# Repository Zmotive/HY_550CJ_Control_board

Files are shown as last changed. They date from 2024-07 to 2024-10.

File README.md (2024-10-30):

# Overview #

Please review the license for use. 

This Project is still under development and not all features have been tested. As I work through the hardware I will continue to update. it is best to test this code will small actuators and another remote control unit prior to installing into an HY-550CJ. 

The HY-550CJ is a dangerous piece of equipment, any code that isn't tested should not be trusted as the machine is capable of serious injury to the user. In no way does the Authors or Contributors accept liability for damage to property or persons in use of this code or hardware. Care must be taken when using this repository. This same controller can be modified to fit other systems as it leverages the RC standard for control. It is best to test this on a safer piece of equipment (or remove the blades from the HY-550CJ prior to testing). 

This code is unable to control the output of the motors when the "Auto" Switch is open (in the off state). The Teensy outputs the power on its auto pin that then runs to the physical switch. This ensures that the device cannot override an operator's manual control. Unfortunately this switch must be located on the machine. 

[@ztokAutomates](https://www.youtube.com/@ztokautomates) will be covering safety of use of this equipment and hazards that operators, programmers, and contributors should be aware of prior to use.   

# Safety #

Do a risk assesment according to ISO 12100 to understand the risks. The following notes below are only a small subset of the most dangerous hazards associated with the machine.

* When working on the blades, disconnect the sparkplug to keep from unexpected engine startup.
* Never place yourself inbetween the machine and a fixed object. The crushing hazard is the one of the most dangerous hazards assocated with the base (not including the blades)
* It is possible to get entangled into the machine tracks, make sure to power off the machine and controller before working on the tracks. Do not underestimate the power and speed of unexpected movement.
* Do Not Ride the Machine. It does have enough power to move people on it but with all of the risks of the tracks, blades, and engine; there is no safe way to ride it. If the intent is to ride the machine then add that task to the risk assesment to understand what hazards you will need to protect from (including rollover).
* When doing the risk assesment ensure to take into account bystandards that will not know about any of these risks (people assume machines are safe and are not hazardous). It is the operator's reponsibilty to keep people safe and understand the hazards assocated with the machine (this is typically accomplished with signs).
* Only use the charger that came with the machine. The port on the machine to charge it is a standard IEC Plug used on 120VAC systems. This Plug on the equpment is actually a 12VDC circuit and plugging it into the wall can cause the frame to be engergized and destroy the control system within the machine and can lead to fire.
* This machine has not been evaluated by any NRTLs (Nationally Recoginized Testing Labratories, like NSF or UL). It is possible (although unlikely) that this system may catch fire if care is not taken.
* There is no rollover cutoff on the machine. if the machine rolls over it will damage the engine. Climbing hills can also damage the engine if constantly doing hills. Give the machine a break if doing a lot of hills. [Video Snipit](https://www.youtube.com/watch?v=2dOWbkyhdJA&t=2900s)
* There is a possibily of debris being ejected from under the machine, wear protective equipment when operating it. The most dangerous places to be are infront and behind the equipment. It can also be ejected from the sides. [It has reached over 10ft in my experience (standing behing it)](https://www.youtube.com/watch?v=2dOWbkyhdJA&t=3720s). Be mindeful of this when operating it.

## Limits ##
* Maximum flat pull force > 300 lbsf (the belts do not stop at this force)
* Maximum speed < ~ 300mm/s (1 ft/s)
* Maximum climb angle < 45 degrees in the forward direction.  

# Setup #
* The Teensy needs to be setup to disable being powered from the USB port to enable debugging under power. [Teensy Reference](https://www.pjrc.com/teensy/external_power.html)
* J1 on the board links the Board 5Vdc to the Motor and Input 5Vdc to power the controller and smaller motors. it should not be used when in the HY-550CJ since power comes from the motor controllers.

# Parts #
 
 [Mouser Project](https://www.mouser.com/ProjectManager/ProjectDetail.aspx?AccessID=017e74ae19)

 Teensy4.1 and GPS boards (2x for robot, 1x for base station) are seperate.
 [GPS Board](https://www.sparkfun.com/products/16481)

 Headers and Sockets included for Teensy and GPS boards.

 [HY-550CJ](https://www.alibaba.com/product-detail/FREE-SHIPPING-CE-EPA-Remote-Control_1600909334029.html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)

 [Base Station Radio 100mW 915Mhz](https://holybro.com/products/sik-telemetry-radio-v3?variant=41562952302781)

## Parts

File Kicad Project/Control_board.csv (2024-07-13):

Source: | C:\Users\Zack\Documents\AGV Board\Control_board\Control_board.kicad_sch
Date: | 7/12/2024 6:36:46 PM
Tool: | Eeschema (7.0.0)
Generator: | C:\Program Files\KiCad\7.0\bin\scripting\plugins/bom_csv_grouped_by_value.py
Component Count: | 55
Collated Components:
Item | Qty | Reference(s) | Value | LibPart | Footprint | Datasheet | DNP | Height | Manufacturer_Name | Manufacturer_Part_Number | Mouser Part Number | Mouser Price/Stock | Sim.Device | Sim.Pins
1 | 5 | 5VOut1, 12VOut1, EKill1, EStart1, SWA1 | Conn_01x02_Pin | Connector:Conn_01x02_Pin | Connector_Phoenix_MC_HighVoltage:PhoenixContact_MCV_1,5_2-G-5.08_1x02_P5.08mm_Vertical | ~
2 | 8 | A3C1, A3M1, A4C1, A4M1, IL1, IR1, ML1, MR1 | Conn_01x03_Pin | Connector:Conn_01x03_Pin | Connector_PinHeader_2.54mm:PinHeader_1x03_P2.54mm_Vertical | ~
3 | 2 | D1, D2 | 1N4001 | Diode:1N4001 | Diode_THT:D_DO-41_SOD81_P10.16mm_Horizontal | http://www.vishay.com/docs/88503/1n4001.pdf |  |  |  |  |  |  |  | D | 1=K 2=A
4 | 4 | IC1, IC2, IC3, IC4 | CNY74-2H | SamacSys:CNY74-2H | DIP762W56P254L977H470Q8N | https://componentsearchengine.com/Datasheets/2/CNY74-2H.pdf |  |  | 4.7 | Vishay | CNY74-2H | 782-CNY74-2H | https://www.mouser.co.uk/ProductDetail/Vishay-Semiconductors/CNY74-2H?qs=xCMk%252BIHWTZO%2Fp2dB7mb0lQ%3D%3D
5 | 2 | IMU1, Radio1 | Conn_01x04_Pin | Connector:Conn_01x04_Pin | Connector_PinHeader_2.54mm:PinHeader_1x04_P2.54mm_Vertical | ~
6 | 1 | J1 | Conn_01x02_Pin | Connector:Conn_01x02_Pin | Connector_PinHeader_2.54mm:PinHeader_1x02_P2.54mm_Vertical | ~
7 | 2 | K1, K5 | SR11-3V-200-2C | SamacSys:SR11-3V-200-2C | SR113V2002C | https://www.cuidevices.com/product/resource/sr11.pdf |  |  | 11.7 | CUI Devices | SR11-3V-200-2C | 179-SR11-3V-200-2C | https://www.mouser.co.uk/ProductDetail/CUI-Devices/SR11-3V-200-2C?qs=4ASt3YYao0Upd1omJxk2Og%3D%3D
8 | 1 | K2 | SR5-12V-200-1C | SamacSys:SR5-12V-200-1C | SR512V2001C | https://www.cuidevices.com/product/resource/sr5.pdf |  |  | 12.1 | CUI Devices | SR5-12V-200-1C | 179-SR5-12V-200-1C | https://www.mouser.co.uk/ProductDetail/CUI-Devices/SR5-12V-200-1C?qs=4ASt3YYao0WMNY1cu6cO0A%3D%3D
9 | 1 | K3 | SR5-3V-200-1C | :SR5-3V-200-1C_1 | SR53V2001C | https://www.cuidevices.com/product/resource/sr5.pdf |  |  | 12.1 | CUI Devices | SR5-3V-200-1C | 179-SR5-3V-200-1C | https://www.mouser.co.uk/ProductDetail/CUI-Devices/SR5-3V-200-1C?qs=4ASt3YYao0XB60H1Ojp4Wg%3D%3D
10 | 1 | K4 | SR5-3V-200-1C | SamacSys:SR5-3V-200-1C | SR53V2001C | https://www.cuidevices.com/product/resource/sr5.pdf |  |  | 12.1 | CUI Devices | SR5-3V-200-1C | 179-SR5-3V-200-1C | https://www.mouser.co.uk/ProductDetail/CUI-Devices/SR5-3V-200-1C?qs=4ASt3YYao0XB60H1Ojp4Wg%3D%3D
11 | 1 | LED1 | 550-1307-004F | SamacSys:550-1307-004F | 5501307004F | https://s3-us-west-2.amazonaws.com/catsy.557/C17646.pdf |  |  | 6.351 | Dialight | 550-1307-004F | 645-550-1307-004F | https://www.mouser.co.uk/ProductDetail/Dialight/550-1307-004F?qs=0KZIkTEbAAuDZRCbhcaU%252Bg%3D%3D
12 | 1 | LEFT-GPS1 | ~ | Boards:SparkFun_GPS-RTK | boards:Sparkfun GPS-RTK
13 | 1 | PS1 | THL_15-2411WI | SamacSys:THL_15-2411WI | THL152411WI | https://tracopower.com/thl15wi-datasheet/ |  |  | 10.66 | Traco Power | THL 15-2411WI | 495-THL15-2411WI | https://www.mouser.co.uk/ProductDetail/TRACO-Power/THL-15-2411WI?qs=vLWxofP3U2zTxW0y6%2FAPOg%3D%3D
14 | 1 | PWR_InF1 | Conn_01x03_Pin | Connector:Conn_01x03_Pin | Connector_Phoenix_MC_HighVoltage:PhoenixContact_MCV_1,5_3-G-5.08_1x03_P5.08mm_Vertical | ~
15 | 2 | R1, R3 | 750 | Device:R | Resistor_THT:R_Axial_DIN0411_L9.9mm_D3.6mm_P12.70mm_Horizontal | ~
16 | 1 | R2 | 6.8K | Device:R | Resistor_THT:R_Axial_DIN0411_L9.9mm_D3.6mm_P12.70mm_Horizontal | ~
17 | 1 | R4 | 1.6K | Device:R | Resistor_THT:R_Axial_DIN0411_L9.9mm_D3.6mm_P12.70mm_Horizontal | ~
18 | 4 | R5, R6, R18, R20 | 187 | Device:R | Resistor_THT:R_Axial_DIN0411_L9.9mm_D3.6mm_P12.70mm_Horizontal | ~
19 | 8 | R7, R8, R9, R10, R13, R14, R15, R16 | 10K | Device:R | Resistor_THT:R_Axial_DIN0411_L9.9mm_D3.6mm_P12.70mm_Horizontal | ~
20 | 4 | R11, R12, R17, R19 | 100 | Device:R | Resistor_THT:R_Axial_DIN0411_L9.9mm_D3.6mm_P12.70mm_Horizontal | ~
21 | 1 | RIGHT-GPS1 | ~ | :SparkFun_GPS-RTK_1 | boards:Sparkfun GPS-RTK
22 | 1 | U1 | Teensy4.1 | Teensy:Teensy4.1 | Teensy:Teensy41
23 | 2 | U2, U3 | 01530007Z | SamacSys:01530007Z | 01530007Z | http://m.littelfuse.com/~/media/commercial-vehicle/datasheets/automotive-fuse-holders/mini/littelfuse_fuse-holders-mini-153-pc-datasheet.pdf |  |  | 7 | LITTELFUSE | 01530007Z | 576-01530007Z | https://www.mouser.co.uk/ProductDetail/Littelfuse/01530007Z?qs=gu7KAQ731URFnx4B9aYM4g%3D%3D

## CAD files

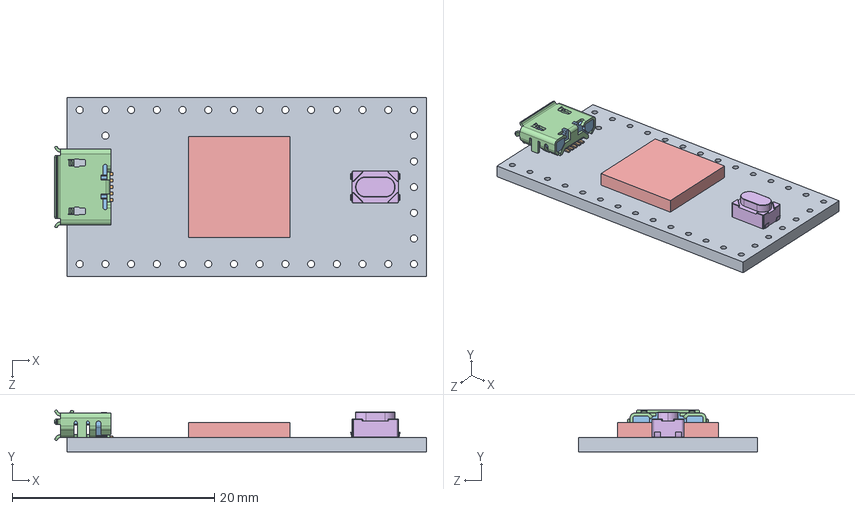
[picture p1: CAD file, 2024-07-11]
Kicad Project/asBuilts/teensy.pretty-master/teensy.pretty-master/Teensy_4.0_Assembly.STEP
36.8 x 4.12 x 17.7 mm
Teensy_4.0_PCB
Micro USB-B Female 5Pin SMD
NXP iMXRT1062
SKRPACE010 v4

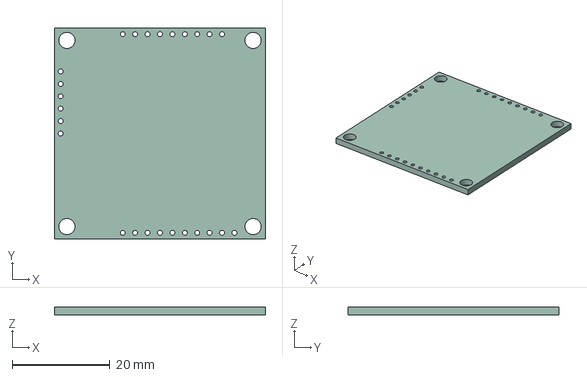
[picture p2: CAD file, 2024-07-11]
Kicad Project/asBuilts/Qwiic_GPS-RTK-SMA_-_ublox_ZED-F9P/Qwiic GPS-RTK-SMA - ublox ZED-F9P Template.step
43.2 x 43.2 x 1.60 mm

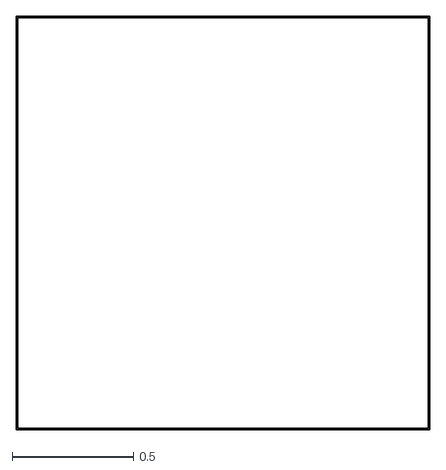
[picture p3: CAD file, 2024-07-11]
Kicad Project/asBuilts/Qwiic_GPS-RTK-SMA_-_ublox_ZED-F9P/Qwiic GPS-RTK-SMA - ublox ZED-F9P Template-Edge_Cuts.dxf
1.71 x 1.71

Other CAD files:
Kicad Project/asBuilts/Qwiic_GPS-RTK-SMA_-_ublox_ZED-F9P/Qwiic GPS-RTK-SMA - ublox ZED-F9P Template-F_Mask.dxf
Kicad Project/asBuilts/Qwiic_GPS-RTK-SMA_-_ublox_ZED-F9P/Qwiic GPS-RTK-SMA - ublox ZED-F9P Template-F_Silkscreen.dxf

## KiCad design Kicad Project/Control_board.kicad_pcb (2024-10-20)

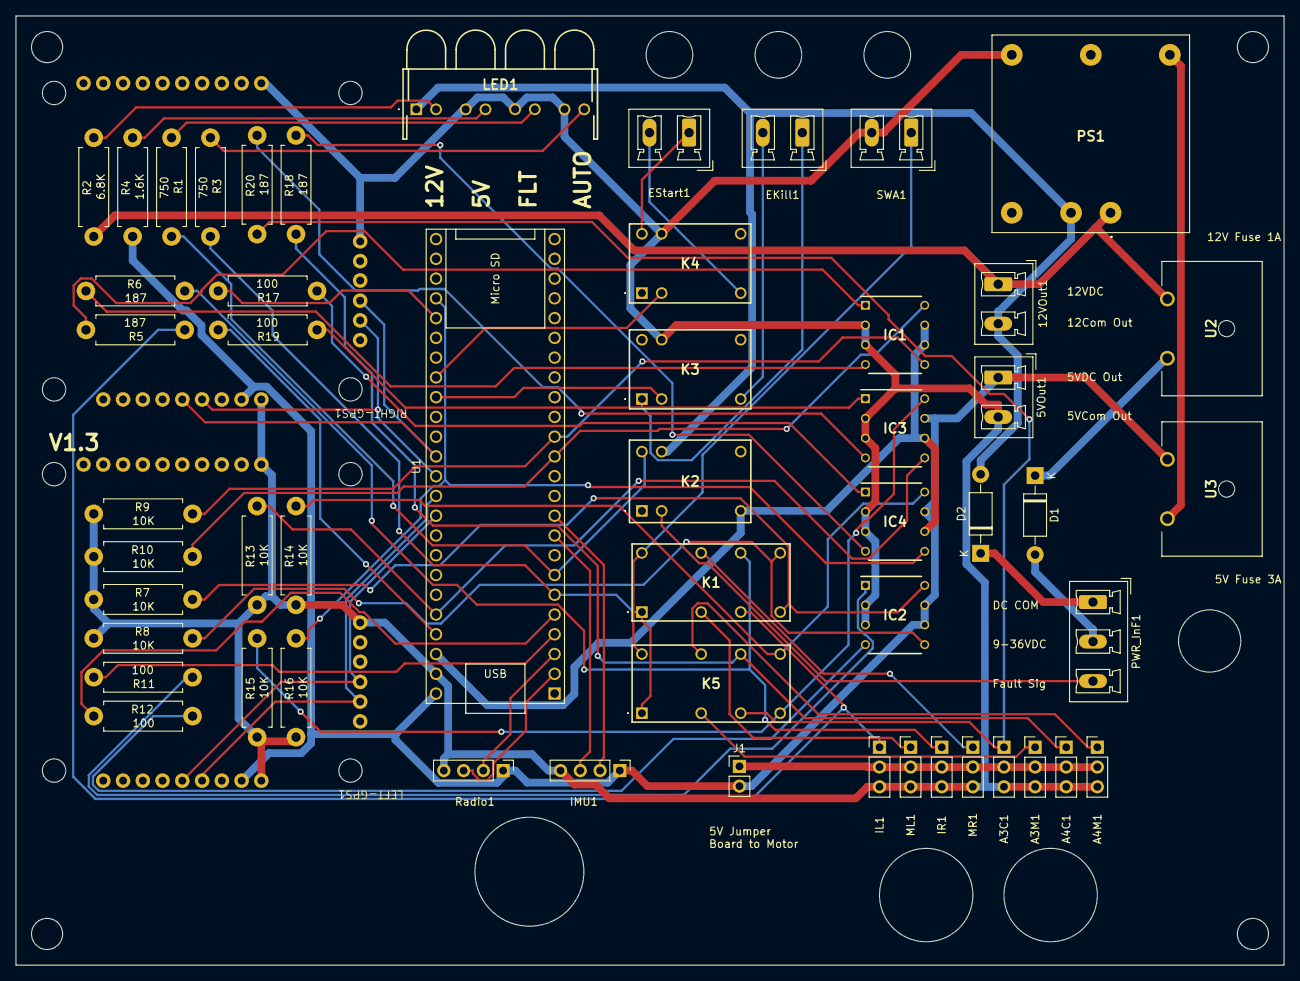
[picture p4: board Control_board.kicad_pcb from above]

Board: 2 copper layers, 163.0 x 122.0 mm, 55 parts (0 on the bottom side), 60 nets.

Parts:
5VOut1, 12VOut1: Conn_01x02_Pin; PhoenixContact_MCV_1,5_2-G-5.08_1x02_P5.08mm_Vertical
A3C1, A3M1, A4C1, A4M1: Conn_01x03_Pin; PinHeader_1x03_P2.54mm_Vertical
D1, D2: 1N4001; D_DO-41_SOD81_P10.16mm_Horizontal
EKill1: Conn_01x02_Pin; PhoenixContact_MCV_1,5_2-G-5.08_1x02_P5.08mm_Vertical
EStart1: Conn_01x02_Pin; PhoenixContact_MCV_1,5_2-G-5.08_1x02_P5.08mm_Vertical
IC1, IC2, IC3, IC4: CNY74-2H; DIP762W56P254L977H470Q8N
IL1: Conn_01x03_Pin; PinHeader_1x03_P2.54mm_Vertical
IMU1: Conn_01x04_Pin; PinHeader_1x04_P2.54mm_Vertical
IR1: Conn_01x03_Pin; PinHeader_1x03_P2.54mm_Vertical
J1: Conn_01x02_Pin; PinHeader_1x02_P2.54mm_Vertical
K1, K5: SR11-3V-200-2C; SR113V2002C
K2: SR5-12V-200-1C; SR512V2001C
K3, K4: SR5-3V-200-1C; SR53V2001C
LED1: 550-1307-004F; 5501307004F
LEFT-GPS1: Sparkfun GPS-RTK
ML1: Conn_01x03_Pin; PinHeader_1x03_P2.54mm_Vertical
MR1: Conn_01x03_Pin; PinHeader_1x03_P2.54mm_Vertical
PS1: THL_15-2411WI; THL152411WI
PWR_InF1: Conn_01x03_Pin; PhoenixContact_MCV_1,5_3-G-5.08_1x03_P5.08mm_Vertical
R1, R3: 750; R_Axial_DIN0411_L9.9mm_D3.6mm_P12.70mm_Horizontal_ZT
R2: 6.8K; R_Axial_DIN0411_L9.9mm_D3.6mm_P12.70mm_Horizontal_ZT
R4: 1.6K; R_Axial_DIN0411_L9.9mm_D3.6mm_P12.70mm_Horizontal_ZT
R5, R6, R18, R20: 187; R_Axial_DIN0411_L9.9mm_D3.6mm_P12.70mm_Horizontal_ZT
R7, R8, R9, R10, R13, R14, R15, R16: 10K; R_Axial_DIN0411_L9.9mm_D3.6mm_P12.70mm_Horizontal_ZT
R11, R12, R17, R19: 100; R_Axial_DIN0411_L9.9mm_D3.6mm_P12.70mm_Horizontal_ZT
RIGHT-GPS1: Sparkfun GPS-RTK
Radio1: Conn_01x04_Pin; PinHeader_1x04_P2.54mm_Vertical
SWA1: Conn_01x02_Pin; PhoenixContact_MCV_1,5_2-G-5.08_1x02_P5.08mm_Vertical
U1: Teensy4.1; Teensy41
U2, U3: 01530007Z

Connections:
3.3V: IC1.6 (CE_2), IC1.7 (CE_1), IC3.6 (CE_2), IC4.6 (CE_2), K2.3 (COM_1), U1.46 (3V3)
5VDC: 5VOut1.1, IC2.6 (CE_2), IC2.7 (CE_1), IC3.7 (CE_1), IC4.7 (CE_1), IMU1.1, J1.2, LEFT-GPS1.8 (5V), R4.1, RIGHT-GPS1.8 (5V), Radio1.1, U1.48 (VIN), U3.2
5VDC_A: PS1.3 (+VOUT), U3.1
12COM: D2.1 (K), PWR_InF1.1
12COM_C: 12VOut1.2, D2.2 (A), K2.5 (COIL_2), LED1.1 (K_GREEN_1), PS1.2 (-VIN_(GND))
12VDC: D1.2 (A), PWR_InF1.2
12VDC_A: D1.1 (K), U2.1
12VDC_C: 12VOut1.1, PS1.1 (+VIN_(VCC)), R2.1, U2.2
A3C_IN: IC3.5 (E_2), R13.2, U1.44 (22_A8_CTX1)
A3M_OUT: R19.2, U1.45 (23_A9_CRX1_MCLK1)
A4C_IN: IC4.5 (E_2), R16.2, U1.28 (36_CS)
A4M_OUT: R17.2, U1.29 (37_CS)
COM: 5VOut1.2, A3C1.3, A3M1.3, A4C1.3, A4M1.3, IC1.2 (C_1), IC1.3 (C_2), IC2.2 (C_1), IC2.3 (C_2), IC3.2 (C_1), IC3.3 (C_2), IC4.2 (C_1), IC4.3 (C_2), IL1.3, IMU1.4, IR1.3, K3.5 (COIL_2), K4.5 (COIL_2), LED1.3 (K_GREEN_2), LED1.5 (K_GREEN_3), LED1.7 (K_GREEN_4), LEFT-GPS1.9 (GND), ML1.3, MR1.3, PS1.5 (-VOUT), R7.1, R8.1, R9.1, R10.1, R13.1, R14.1, R15.1, R16.1, RIGHT-GPS1.9 (GND), Radio1.4, SWA1.2, U1.47 (GND)
EKill: K3.2 (COIL_1), U1.33 (41_A17)
EStart: K4.2 (COIL_1), U1.32 (40_A16)
M5V: A3C1.2, A3M1.2, A4C1.2, A4M1.2, IL1.2, IR1.2, J1.1, ML1.2, MR1.2
MCom: K1.8 (COIL_2), K5.8 (COIL_2), SWA1.1
MOut: K1.1 (COIL_1), K5.1 (COIL_1), R3.2, U1.6 (4_BCLK2)
unnamed: A3C1.1, K5.3 (NC_1), R20.1
unnamed: A3M1.1, K5.2 (COM_1)
unnamed: A4C1.1, K5.6 (NC_2), R18.1
unnamed: A4M1.1, K5.7 (COM_2)
unnamed: EKill1.1, K3.1 (NC)
unnamed: EKill1.2, K3.3 (COM_1)
unnamed: EStart1.1, K4.6 (NO)
unnamed: EStart1.2, K4.3 (COM_1)
unnamed: IC1.1 (A_1), R5.2
unnamed: IC1.4 (A_2), R6.1
unnamed: IC1.8 (E_1), R10.2, U1.13 (11_MOSI_CTX1)
unnamed: IC1.5 (E_2), R9.2, U1.14 (12_MISO_MQSL)
unnamed: IC2.1 (A_1), R11.1
unnamed: IC2.4 (A_2), R12.2
unnamed: IC2.8 (E_1), K1.4 (NO_1), R7.2
unnamed: IC2.5 (E_2), K1.5 (NO_2), R8.2
unnamed: IC3.1 (A_1), R19.1
unnamed: IC3.4 (A_2), R20.2
unnamed: IC3.8 (E_1), K5.4 (NO_1), R15.2
unnamed: IC4.1 (A_1), R17.1
unnamed: IC4.4 (A_2), R18.2
unnamed: IC4.8 (E_1), K5.5 (NO_2), R14.2
unnamed: IL1.1, K1.3 (NC_1), R5.1
unnamed: IR1.1, K1.6 (NC_2), R6.2
unnamed: K1.2 (COM_1), ML1.1
unnamed: K1.7 (COM_2), MR1.1
unnamed: K2.2 (COIL_1), PWR_InF1.3
unnamed: K2.6 (NO), R1.2, U1.7 (5_IN2)
unnamed: LED1.2 (A_GREEN_1), R2.2
unnamed: LED1.4 (A_GREEN_2), R4.2
unnamed: LED1.6 (A_GREEN_3), R1.1
unnamed: LED1.8 (A_GREEN_4), R3.1
unnamed: LEFT-GPS1.5 (RX2), U1.39 (17_A3_TX4_SDA1)
unnamed: LEFT-GPS1.6 (TX2), U1.38 (16_A2_RX4_SCL1)
unnamed: RIGHT-GPS1.5 (RX2), U1.36 (14_A0_TX3_SPDIF_OUT)
unnamed: RIGHT-GPS1.6 (TX2), U1.37 (15_A1_RX3_SPDIF_IN)
unnamed: R11.2, U1.4 (2_OUT2)
unnamed: R12.1, U1.5 (3_LRCLK2)
RX1: Radio1.3, U1.2 (0_RX1_CRX2_CS1)
RX2: IMU1.3, U1.9 (7_RX2_OUT1A)
TX1: Radio1.2, U1.3 (1_TX1_CTX2_MISO1)
TX2: IMU1.2, U1.10 (8_TX2_IN1)

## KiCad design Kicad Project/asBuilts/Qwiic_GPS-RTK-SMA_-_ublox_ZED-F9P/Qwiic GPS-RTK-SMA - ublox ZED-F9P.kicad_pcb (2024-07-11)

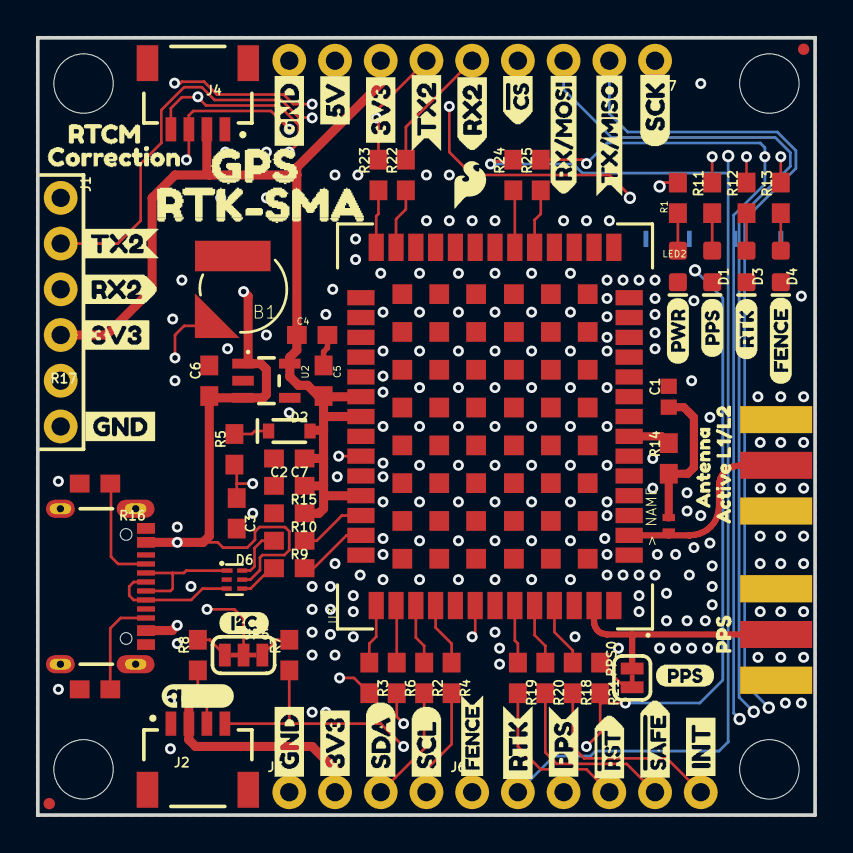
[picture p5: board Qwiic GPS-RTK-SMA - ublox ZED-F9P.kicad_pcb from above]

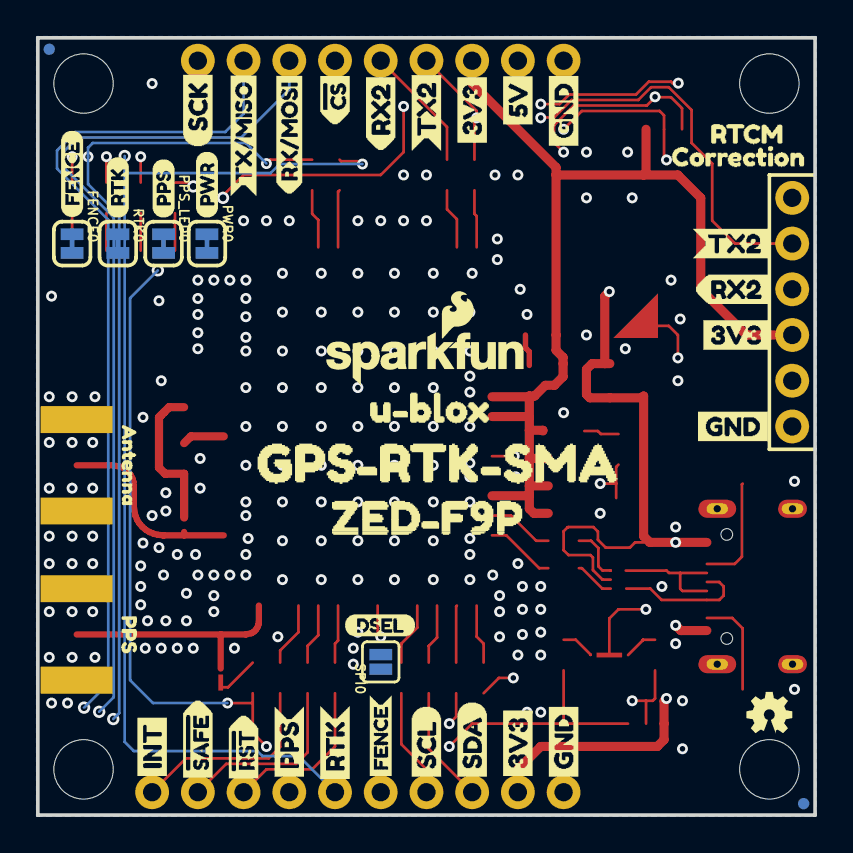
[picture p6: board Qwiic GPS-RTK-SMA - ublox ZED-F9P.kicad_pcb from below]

Board: 4 copper layers, 43.2 x 43.2 mm, 143 parts (44 on the bottom side), 52 nets.

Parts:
B1: 6.8MM_COIN_CELL; ML414H_IV01E
C1: 47pF; 0402
C2, C3, C4, C6: 1.0uF; 0603
C5, C7: 0.1uF; 0603
D1: Yellow; LED-0603
D2: 0.5A/40V/420mV; SOD-323
D3: GREEN; LED-0603
D4: BLUE; LED-0603
D6: PRTR5V0U2F; SOT886
E1, E2: SMA; SMA-EDGE
FB1: 120NH; 0402_MURATA
FENCE0: SMT-JUMPER_2_NC_TRACE_SILK
FRAME2: FRAME-LEDGER; CREATIVE_COMMONS
J1: Radio; 1X06_NO_SILK
J2, J4: Qwiic Right Angle; JST04_1MM_RA
J3: PTH; 1X04_NO_SILK
J5: USB-C-16P-2LAYER-PADS
J6: 1X06_NO_SILK
J7: 1X09_NO_SILK
JP5: SMT-JUMPER_3_2-NC_TRACE_SILK
JP21, JP61, JP71, JP81: FIDUCIALUFIDUCIAL; MICRO-FIDUCIAL
JP31, JP41, JP91, JP101: STAND-OFF
LED2: RED; LED-0603
LOGO1: OSHW-LOGOMINI; OSHW-LOGO-MINI
LOGO2: SFE_LOGO_NAME_FLAME.1_INCH; SFE_LOGO_NAME_FLAME_.1
PPS0: SMT-JUMPER_2_NC_TRACE_SILK
PPS_LED0: SMT-JUMPER_2_NC_TRACE_SILK
PWR0: SMT-JUMPER_2_NC_TRACE_SILK
R1, R5, R11, R12, R13: 1k; 0603
R2, R3, R4, R6, R14, R18, R19, R20, R21, R22, R23, R24, R25: 33; 0603
R7, R8: 2.2k; 0603
R9, R10: 27; 0603
R15: 100k; 0603
R16, R17: 5.1k; 0603
RTK0: SMT-JUMPER_2_NC_TRACE_SILK
SPI0: SMT-JUMPER_2_NO_SILK
U2: 3.3V; SOT23-5
U3: ZED-F9P
U$1, U$4: SDA-[)
U$2: SPECIAL_INSTRUCTIONS-ORDERING; ORDERING_INSTRUCTIONS
U$3, U$5: SCL-[)
U$6, U$7, U$60, U$61, U$66, U$67: 3V3-04
U$8, U$9, U$62, U$63: GND-04
U$10: I_SUPER2_C-()-03
U$11, U$54: FENCE2
U$12, U$18: PWR-()-03
U$13, U$28, U$29, U$32: RTK1
U$14, U$17: FENCE0
U$15, U$16: INT8
U$19, U$20: 5V
U$21, U$56, U$58: RX20
U$22: U#BLOX3
U$23, U$24: CS#-_]
U$25, U$52, U$72: PPS0
U$26, U$31: RX#MOSI3
U$27: DSEL0
U$30: QWIIC_4MM
U$33: SFE_LOGO_FLAME_.1
U$34, U$37: TX#MISO1
U$35, U$36: #RST3
U$38, U$41: SCK-(]-04
U$39, U$40: #SAFE1
U$42: RX22
U$43, U$44: PPS5
U$45, U$68: GND3
U$47, U$74: PPS1
U$48, U$70: RTCM5
U$49: ZED#F9P6
U$50, U$55, U$57: TX21
U$51: TX23
U$53, U$69: CORRECTION0
U$59: GPS0
U$65: ACTIVE_L1#L21
U$71, U$75: ANTENNA2
U$73: RTK#SMA4
U$76: GPS#RTK#SMA5

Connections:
3.3V: C2.1, C4.1, C5.2, C7.2, D2.A, J1.4, J2.2, J3.2, J4.2, J7.7, JP5.2, PWR0.2, R15.2, U2.5, U3.33, U3.34, U3.38
5V: C6.1, D6.5, J5.VBUS1, J5.VBUS2, J7.8, U2.1, U2.3
ANT_VCC: C1.1, FB1.P2, R14.1
BACKUP: B1.+, C3.1, R5.1, U3.36
CC1: J5.A5, R17.2
CC2: J5.B5, R16.2
D+: D6.4, R9.1
D-: D6.6, R10.1
D_SEL: SPI0.2, U3.47
FENCE_STAT: FENCE0.2, J6.1, R25.2
GND: B1.-, C1.2, C2.2, C3.2, C4.2, C5.1, C6.2, C7.1, D1.C, D3.C, D4.C, D6.2, E1.GND@0, E1.GND@1, E1.GND@2, E1.GND@3, E2.GND@0, E2.GND@1, E2.GND@2, E2.GND@3, J1.6, J2.1, J3.1, J4.1, J5.GND, J5.GND2, J5.SHLD1, J5.SHLD2, J5.SHLD3, J5.SHLD4, J7.9, LED2.C, R15.1, R16.1, R17.1, SPI0.1, U2.2, U3.1, U3.3, U3.12, U3.14, U3.32, U3.37, U3.41, U3.48, U3.55, U3.56, U3.57, U3.58, U3.59, U3.60, U3.61, U3.62, U3.63, U3.64, U3.65, U3.66, U3.67, U3.68, U3.69, U3.70, U3.71, U3.72, U3.73, U3.74, U3.75, U3.76, U3.77, U3.78, U3.79, U3.80, U3.81, U3.82, U3.83, U3.84, U3.85, U3.86, U3.87, U3.88, U3.89, U3.90, U3.91, U3.92, U3.93, U3.94, U3.95, U3.96, U3.97, U3.98, U3.99, U3.100, U3.101, U3.102
GPS_ANT1: E1.SIG, FB1.P1, U3.2
INT: J6.6, R18.2
unnamed: D3.A, R12.1
unnamed: D1.A, R11.1
unnamed: R12.2, RTK0.1
unnamed: PPS_LED0.1, R11.2
unnamed: JP5.1, R8.2
unnamed: D2.C, R5.2
unnamed: D4.A, R13.1
unnamed: JP5.3, R7.2
unnamed: FENCE0.1, R13.2
unnamed: LED2.A, R1.1
unnamed: R9.2, U3.40
unnamed: R10.2, U3.39
unnamed: R14.2, U3.7
unnamed: R22.1, U3.26
unnamed: R18.1, U3.51
unnamed: R19.1, U3.49
unnamed: PWR0.1, R1.2
unnamed: R20.1, U3.50
unnamed: R24.1, U3.20
unnamed: R25.1, U3.19
unnamed: PPS0.1, R21.1
PPS: E2.SIG, PPS0.2, U3.53
PPS_STAT: J6.3, PPS_LED0.2, R21.2
RTK_STAT: J6.2, R24.2, RTK0.2
RX2: J1.3, J7.5, R22.2
RXI/MOSI: J7.3, R6.2
RXLV: R6.1, U3.43
SCL/SCK: J2.4, J3.4, J4.4, J7.1, R4.2, R7.1
SCL_LV: R4.1, U3.45
SDA/~CS: J2.3, J3.3, J4.3, J7.4, R2.2, R8.1
SDA_LV: R2.1, U3.44
TX2: J1.2, J7.6, R23.2
TX2_P: R23.1, U3.27
TXLV: R3.1, U3.42
TXO/MISO: J7.2, R3.2
UNP_D+: D6.3, J5.A6, J5.B6
UNP_D-: D6.1, J5.A7, J5.B7
~RESET: J6.4, R19.2
~SAFE: J6.5, R20.2

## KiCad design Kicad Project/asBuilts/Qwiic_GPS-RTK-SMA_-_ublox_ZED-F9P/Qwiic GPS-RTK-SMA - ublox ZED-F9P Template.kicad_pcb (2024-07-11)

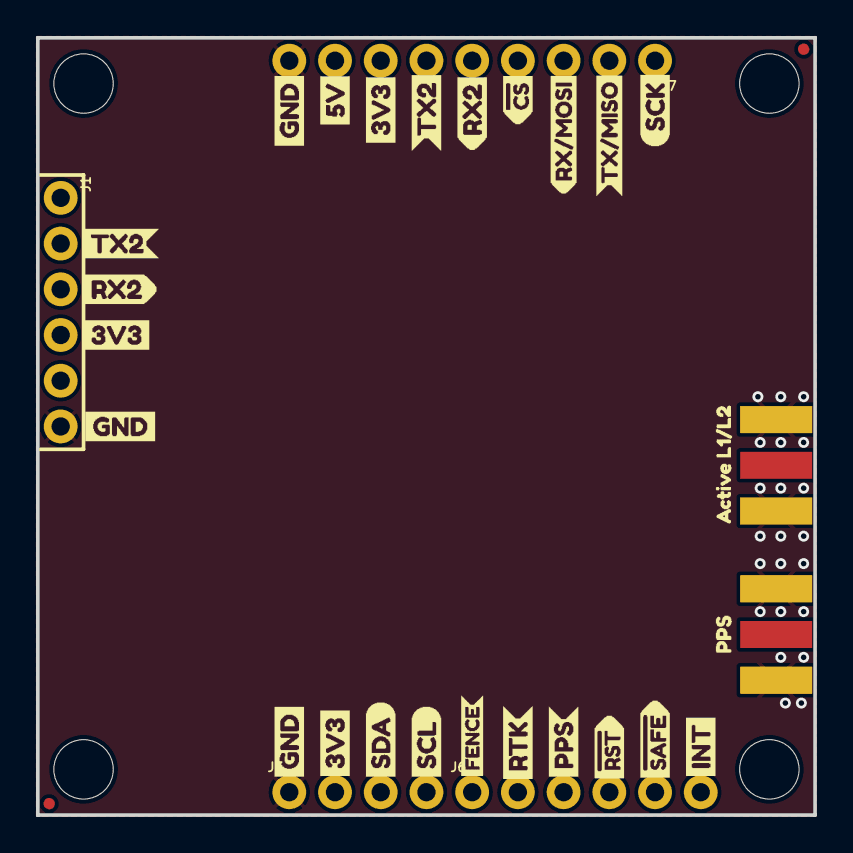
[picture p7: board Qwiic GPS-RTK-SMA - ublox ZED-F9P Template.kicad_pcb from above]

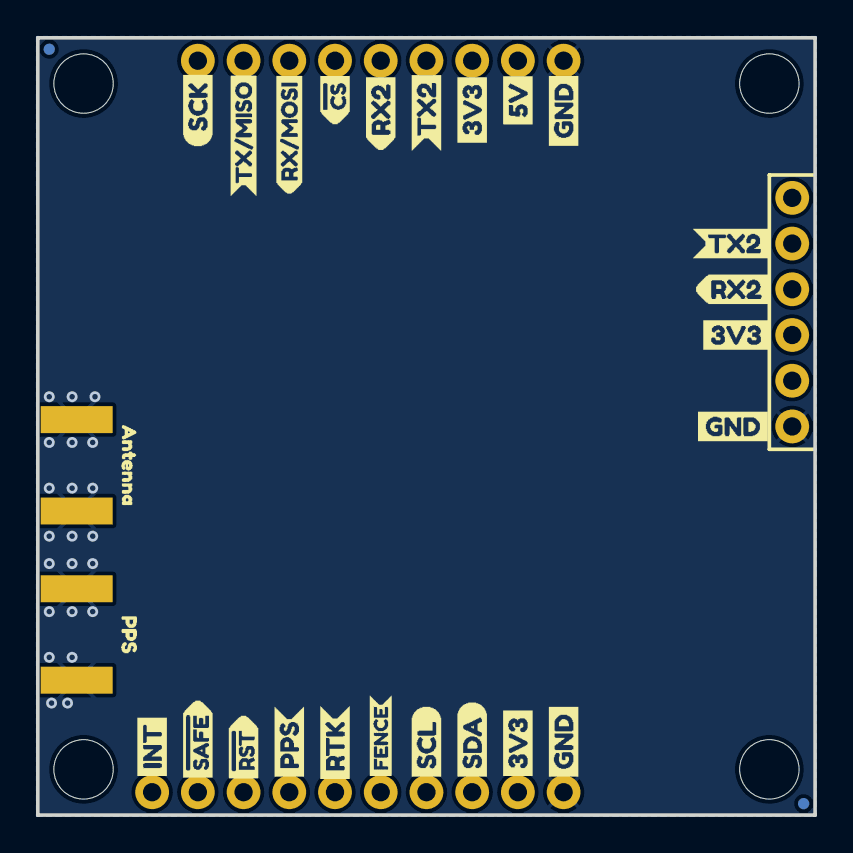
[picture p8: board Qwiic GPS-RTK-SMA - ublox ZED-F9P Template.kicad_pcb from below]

Board: 4 copper layers, 43.2 x 43.2 mm, 64 parts (27 on the bottom side), 6 nets, no tracks yet.

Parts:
E1, E2: SMA; SMA-EDGE
J1: Radio; 1X06_NO_SILK
J3: PTH; 1X04_NO_SILK
J6: 1X06_NO_SILK
J7: 1X09_NO_SILK
JP21, JP61, JP71, JP81: FIDUCIALUFIDUCIAL; MICRO-FIDUCIAL
JP31, JP41, JP91, JP101: STAND-OFF
U$1, U$4: SDA-[)
U$3, U$5: SCL-[)
U$6, U$7, U$60, U$61, U$66, U$67: 3V3-04
U$8, U$9, U$62, U$63: GND-04
U$14, U$17: FENCE0
U$15, U$16: INT8
U$19, U$20: 5V
U$21, U$56, U$58: RX20
U$23, U$24: CS#-_]
U$26, U$31: RX#MOSI3
U$28, U$29: RTK1
U$34, U$37: TX#MISO1
U$35, U$36: #RST3
U$38, U$41: SCK-(]-04
U$39, U$40: #SAFE1
U$42: RX22
U$43, U$44: PPS5
U$45, U$68: GND3
U$47, U$74: PPS1
U$50, U$55, U$57: TX21
U$51: TX23
U$65: ACTIVE_L1#L21
U$75: ANTENNA2

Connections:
3.3V: J1.4, J3.2, J7.7
GND: E1.GND@0, E1.GND@1, E1.GND@2, E1.GND@3, E2.GND@0, E2.GND@1, E2.GND@2, E2.GND@3, J1.6, J3.1, J7.9
RX2: J1.3, J7.5
SCL/SCK: J3.4, J7.1
SDA/~CS: J3.3, J7.4
TX2: J1.2, J7.6

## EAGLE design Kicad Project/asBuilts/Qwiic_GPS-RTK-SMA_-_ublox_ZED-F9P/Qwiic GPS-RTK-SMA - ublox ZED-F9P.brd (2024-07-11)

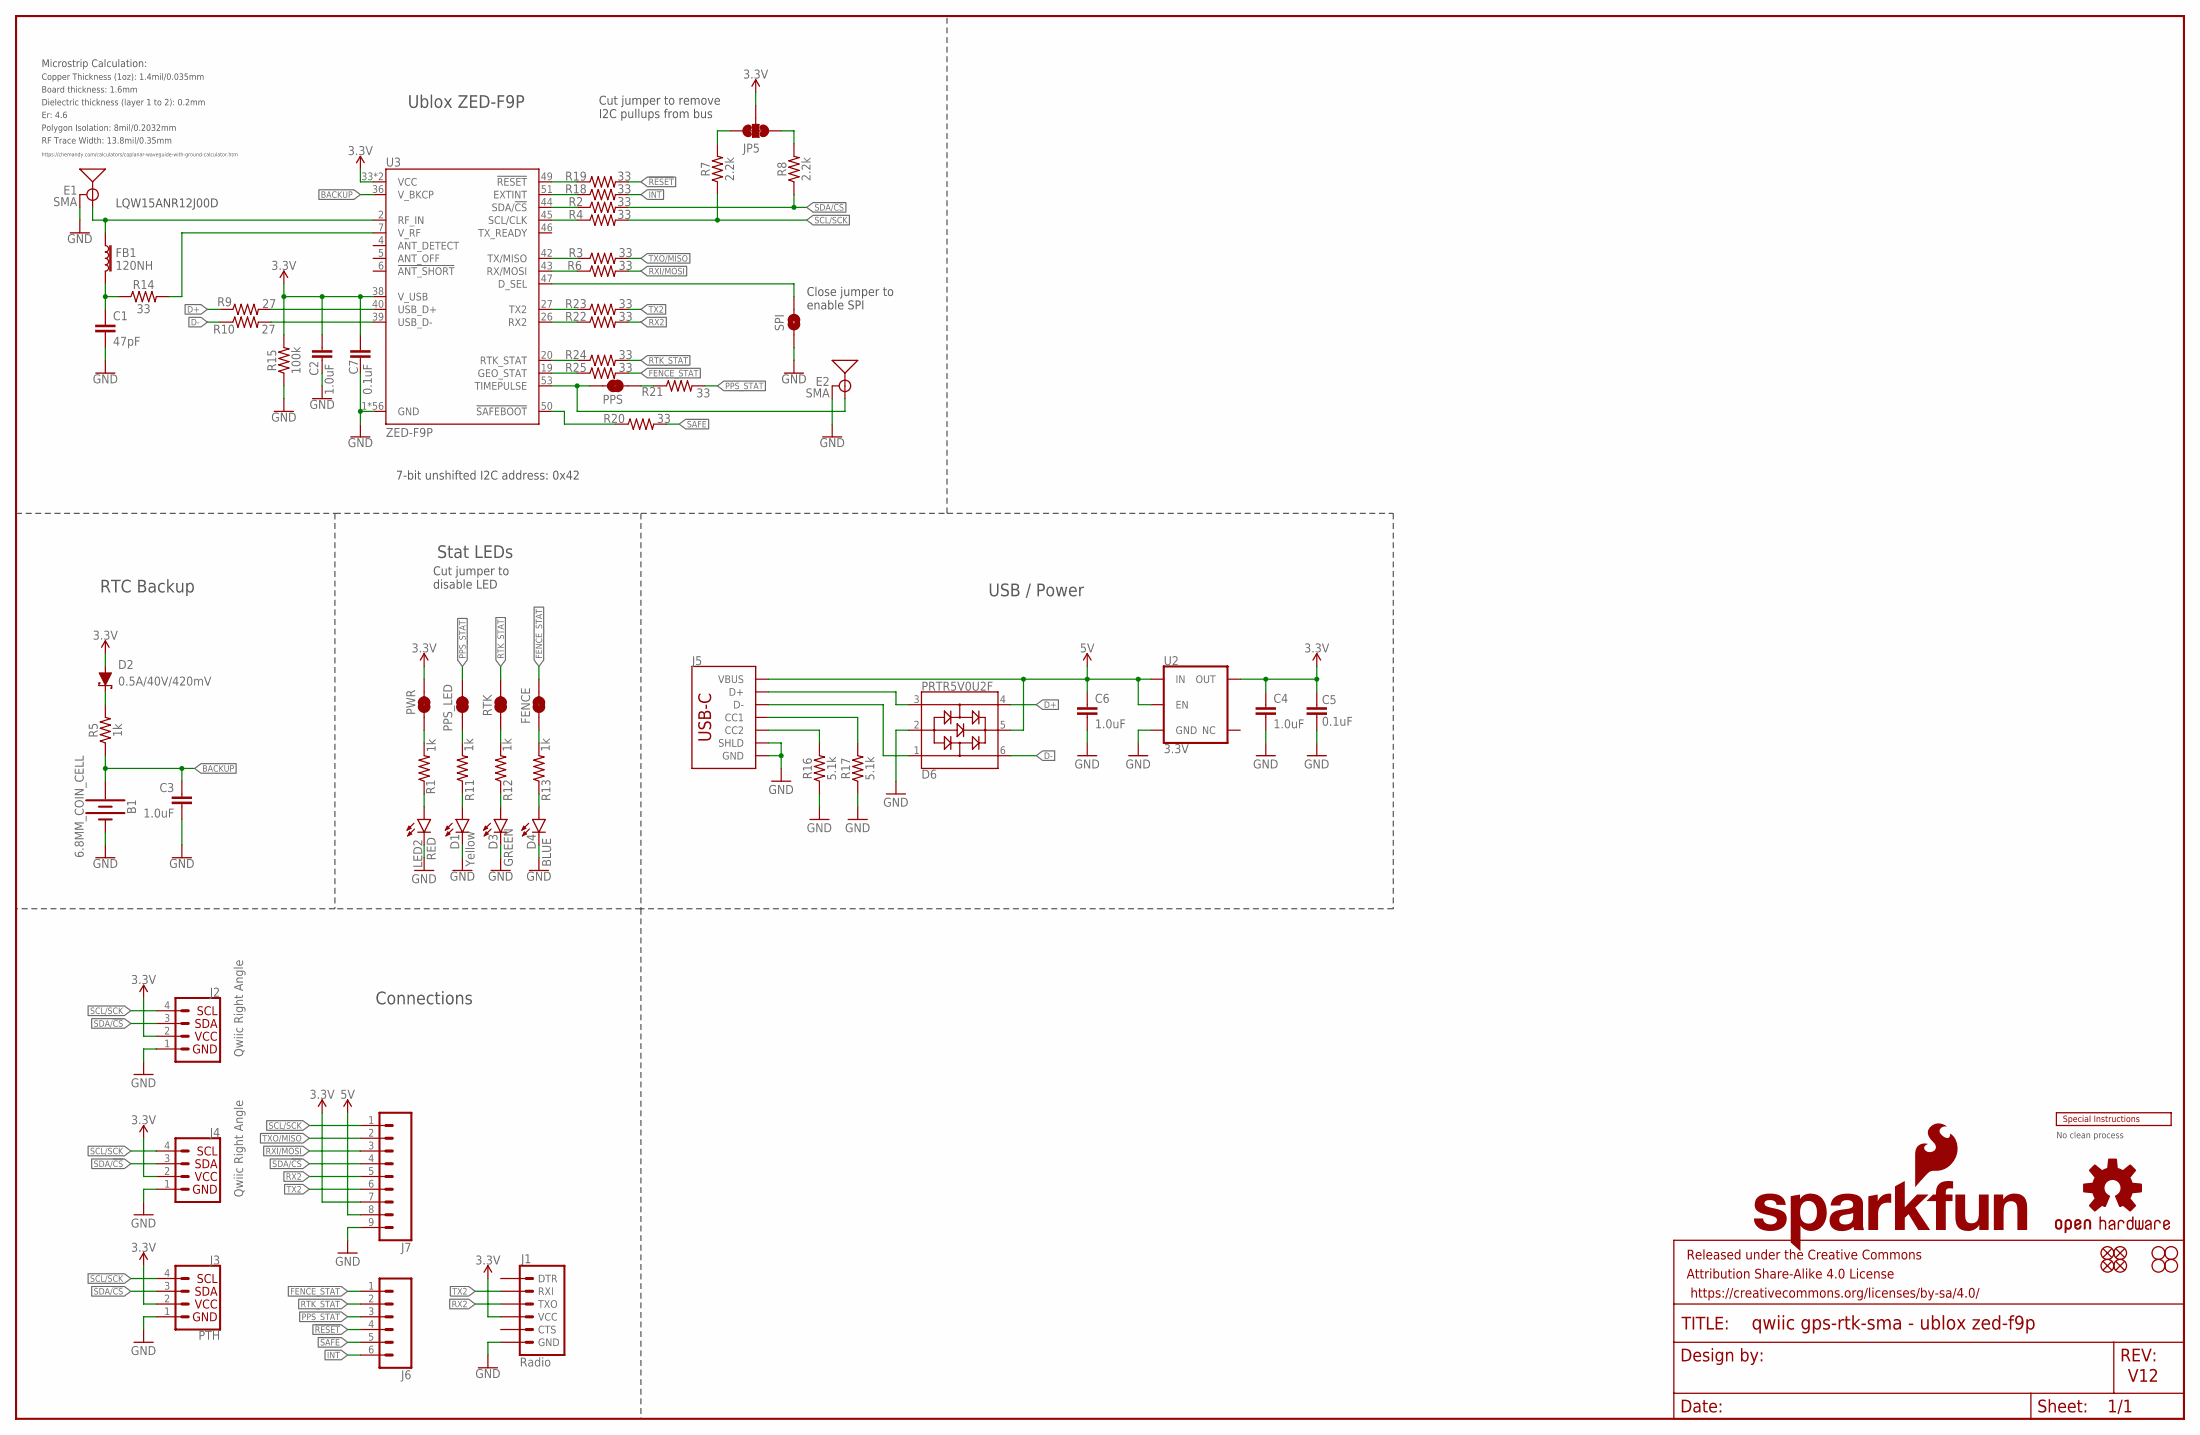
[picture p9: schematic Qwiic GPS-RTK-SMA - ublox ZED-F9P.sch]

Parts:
B1: 6.8MM_COIN_CELL; ML414H_IV01E
C1: 47pF; 0402
C2, C3, C4, C6: 1.0uF; 0603
C5, C7: 0.1uF; 0603
D1: Yellow; LED-0603
D2: 0.5A/40V/420mV; SOD-323
D3: GREEN; LED-0603
D4: BLUE; LED-0603
D6: PRTR5V0U2F; SOT886
E1, E2: SMA; SMA-EDGE
FB1: 120NH; 0402_MURATA
FENCE: JUMPER-SMT_2_NC_TRACE_SILK; SMT-JUMPER_2_NC_TRACE_SILK
FRAME2: FRAME-LEDGER; CREATIVE_COMMONS
J1: Radio; 1X06_NO_SILK
J2, J4: Qwiic Right Angle; JST04_1MM_RA
J3: PTH; 1X04_NO_SILK
J5: USB_C_2-LAYER_PADS; USB-C-16P-2LAYER-PADS
J6: CONN_06NO_SILK_FEMALE_PTH; 1X06_NO_SILK
J7: CONN_09NO_SILK; 1X09_NO_SILK
JP5: JUMPER-SMT_3_2-NC_TRACE_SILK; SMT-JUMPER_3_2-NC_TRACE_SILK
JP21, JP61, JP71, JP81: FIDUCIALUFIDUCIAL; MICRO-FIDUCIAL
JP31, JP41, JP91, JP101: STAND-OFF
LED2: RED; LED-0603
LOGO1: OSHW-LOGOMINI; OSHW-LOGO-MINI
LOGO2: SFE_LOGO_NAME_FLAME.1_INCH; SFE_LOGO_NAME_FLAME_.1
PPS: JUMPER-SMT_2_NC_TRACE_SILK; SMT-JUMPER_2_NC_TRACE_SILK
PPS_LED: JUMPER-SMT_2_NC_TRACE_SILK; SMT-JUMPER_2_NC_TRACE_SILK
PWR: JUMPER-SMT_2_NC_TRACE_SILK; SMT-JUMPER_2_NC_TRACE_SILK
R1, R5, R11, R12, R13: 1k; 0603
R2, R3, R4, R6, R14, R18, R19, R20, R21, R22, R23, R24, R25: 33; 0603
R7, R8: 2.2k; 0603
R9, R10: 27; 0603
R15: 100k; 0603
R16, R17: 5.1k; 0603
RTK: JUMPER-SMT_2_NC_TRACE_SILK; SMT-JUMPER_2_NC_TRACE_SILK
SPI: JUMPER-SMT_2_NO_SILK; SMT-JUMPER_2_NO_SILK
U2: 3.3V; SOT23-5
U3: ZED-F9P
U$2: SPECIAL_INSTRUCTIONS-ORDERING; ORDERING_INSTRUCTIONS

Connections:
3.3V: C2.1, C4.1, C5.2, C7.2, D2.A, J1.4 (VCC), J2.2, J3.2 (VCC), J4.2, J7.7, JP5.2, PWR.2, R15.2, U2.5 (OUT), U3.33 (VCC), U3.34 (VCC), U3.38 (V_USB)
5V: C6.1, D6.5, J5.VBUS1 (VBUS), J5.VBUS2 (VBUS), J7.8, U2.1 (IN), U2.3 (EN)
!RESET: J6.4, R19.2
!SAFE: J6.5, R20.2
ANT_VCC: C1.1, FB1.P2 (2), R14.1
BACKUP: B1.+, C3.1, R5.1, U3.36 (V_BKCP)
CC1: J5.A5 (CC1), R17.2
CC2: J5.B5 (CC2), R16.2
D+: D6.4, R9.1
D-: D6.6, R10.1
D_SEL: SPI.2, U3.47 (D_SEL)
FENCE_STAT: FENCE.2, J6.1, R25.2
GND: B1.-, C1.2, C2.2, C3.2, C4.2, C5.1, C6.2, C7.1, D1.C, D3.C, D4.C, D6.2, E1.GND@0 (GND), E1.GND@1 (GND), E1.GND@2 (GND), E1.GND@3 (GND), E2.GND@0 (GND), E2.GND@1 (GND), E2.GND@2 (GND), E2.GND@3 (GND), J1.6 (GND), J2.1, J3.1 (GND), J4.1, J5.GND, J5.GND2 (GND), J5.SHLD1 (SHLD), J5.SHLD2 (SHLD), J5.SHLD3 (SHLD), J5.SHLD4 (SHLD), J7.9, LED2.C, R15.1, R16.1, R17.1, SPI.1, U2.2 (GND), U3.1 (GND), U3.3 (GND), U3.12 (GND), U3.14 (GND), U3.32 (GND), U3.37 (GND), U3.41 (GND), U3.48 (GND), U3.55 (GND), U3.56 (GND), U3.57 (GND), U3.58 (GND), U3.59 (GND), U3.60 (GND), U3.61 (GND), U3.62 (GND), U3.63 (GND), U3.64 (GND), U3.65 (GND), U3.66 (GND), U3.67 (GND), U3.68 (GND), U3.69 (GND), U3.70 (GND), U3.71 (GND), U3.72 (GND), U3.73 (GND), U3.74 (GND), U3.75 (GND), U3.76 (GND), U3.77 (GND), U3.78 (GND), U3.79 (GND), U3.80 (GND), U3.81 (GND), U3.82 (GND), U3.83 (GND), U3.84 (GND), U3.85 (GND), U3.86 (GND), U3.87 (GND), U3.88 (GND), U3.89 (GND), U3.90 (GND), U3.91 (GND), U3.92 (GND), U3.93 (GND), U3.94 (GND), U3.95 (GND), U3.96 (GND), U3.97 (GND), U3.98 (GND), U3.99 (GND), U3.100 (GND), U3.101 (GND), U3.102 (GND)
GPS_ANT1: E1.SIG (SIGNAL), FB1.P1 (1), U3.2 (RF_IN)
INT: J6.6, R18.2
unnamed: D3.A, R12.1
unnamed: D1.A, R11.1
unnamed: R12.2, RTK.1
unnamed: PPS_LED.1, R11.2
unnamed: JP5.1, R8.2
unnamed: D2.C, R5.2
unnamed: D4.A, R13.1
unnamed: JP5.3, R7.2
unnamed: FENCE.1, R13.2
unnamed: LED2.A, R1.1
unnamed: R9.2, U3.40 (USB_D+)
unnamed: R10.2, U3.39 (USB_D-)
unnamed: R14.2, U3.7 (V_RF)
unnamed: R22.1, U3.26 (RX2)
unnamed: R18.1, U3.51 (EXTINT)
unnamed: R19.1, U3.49 (!RESET!)
unnamed: PWR.1, R1.2
unnamed: R20.1, U3.50 (!SAFEBOOT!)
unnamed: R24.1, U3.20 (RTK_STAT)
unnamed: R25.1, U3.19 (GEO_STAT)
unnamed: PPS.1, R21.1
PPS: E2.SIG (SIGNAL), PPS.2, U3.53 (TIMEPULSE)
PPS_STAT: J6.3, PPS_LED.2, R21.2
RTK_STAT: J6.2, R24.2, RTK.2
RX2: J1.3 (TXO), J7.5, R22.2
RXI/MOSI: J7.3, R6.2
RXLV: R6.1, U3.43 (RX/MOSI)
SCL/SCK: J2.4, J3.4 (SCL), J4.4, J7.1, R4.2, R7.1
SCL_LV: R4.1, U3.45 (SCL/CLK)
SDA/!CS: J2.3, J3.3 (SDA), J4.3, J7.4, R2.2, R8.1
SDA_LV: R2.1, U3.44 (SDA/!CS!)
TX2: J1.2 (RXI), J7.6, R23.2
TX2_P: R23.1, U3.27 (TX2)
TXLV: R3.1, U3.42 (TX/MISO)
TXO/MISO: J7.2, R3.2
UNP_D+: D6.3, J5.A6 (D+), J5.B6 (D+)
UNP_D-: D6.1, J5.A7 (D-), J5.B7 (D-)

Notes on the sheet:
V12
7-bit unshifted I2C address: 0x42
Ublox ZED-F9P
RTC Backup
Stat LEDs
Cut jumper to remove I2C pullups from bus
Cut jumper to disable LED
Close jumper to enable SPI
LQW15ANR12J00D
Board thickness: 1.6mm
Er: 4.6
Copper Thickness (1oz): 1.4mil/0.035mm
RF Trace Width: 13.8mil/0.35mm
Polygon Isolation: 8mil/0.2032mm
No clean process
Dielectric thickness (layer 1 to 2): 0.2mm
https://chemandy.com/calculators/coplanar-waveguide-with-ground-calculator.htm
Microstrip Calculation:
Connections
USB / Power

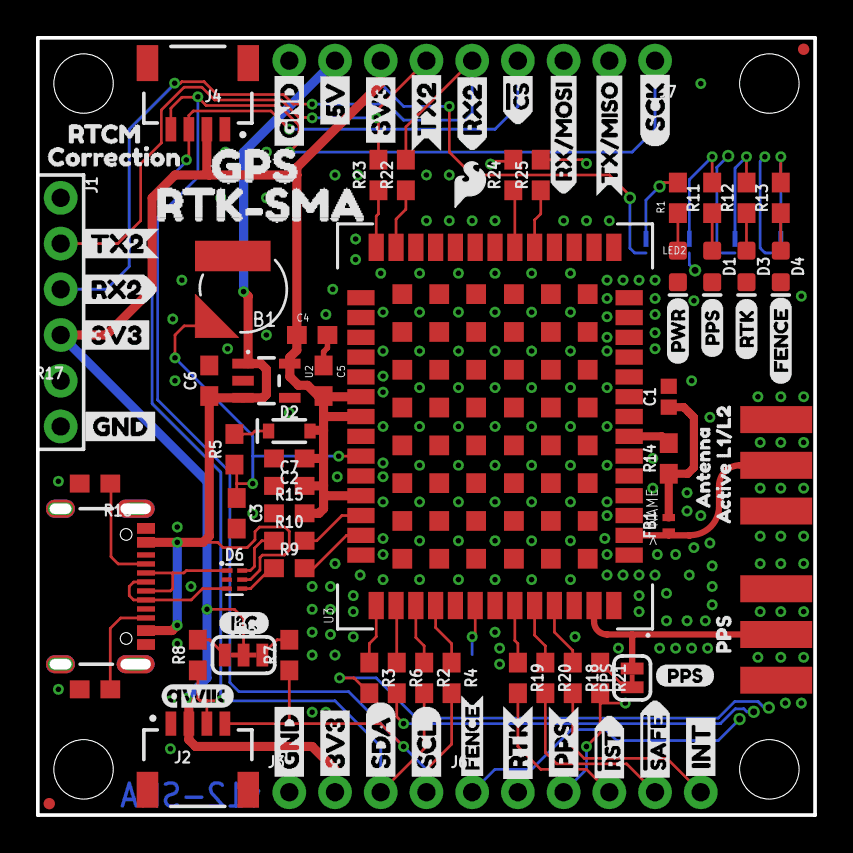
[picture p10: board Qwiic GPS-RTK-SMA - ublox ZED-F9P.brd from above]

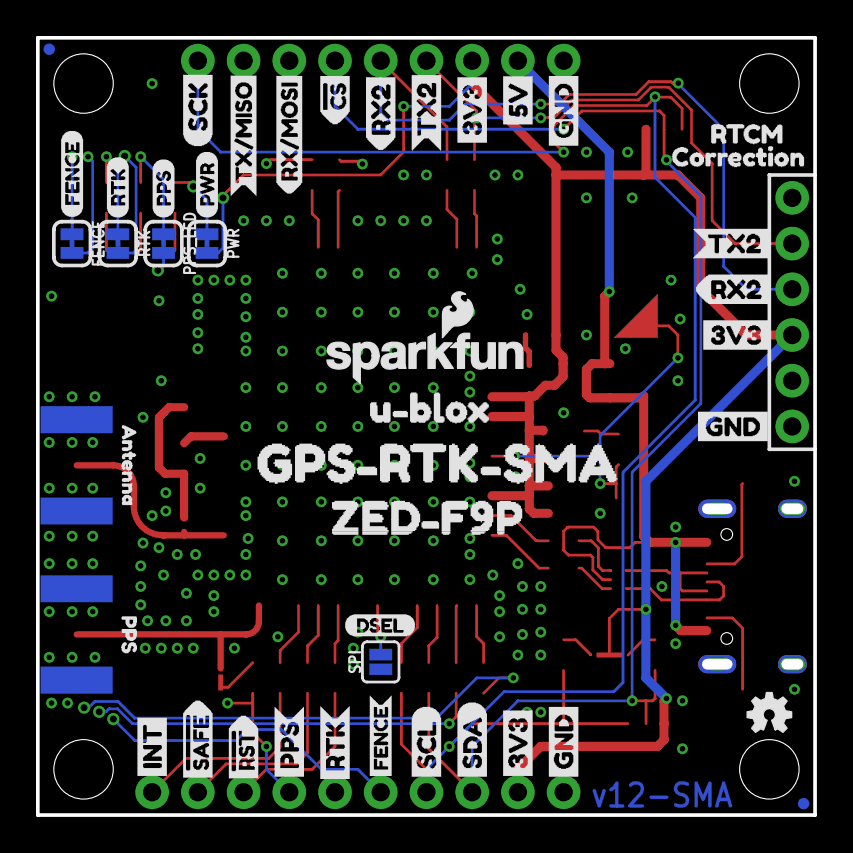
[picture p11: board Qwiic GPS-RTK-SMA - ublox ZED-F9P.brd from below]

Board: 4 copper layers, 43.2 x 43.2 mm, 143 parts (44 on the bottom side), 52 nets.

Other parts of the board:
U$1, U$4: SDA-[)
U$3, U$5: SCL-[)
U$6, U$7, U$60, U$61, U$66, U$67: 3V3-04
U$8, U$9, U$62, U$63: GND-04
U$10: I_SUPER2_C-()-03
U$11, U$54: FENCE2
U$12, U$18: PWR-()-03
U$13, U$28, U$29, U$32: RTK1
U$14, U$17: FENCE0
U$15, U$16: INT8
U$19, U$20: 5V
U$21, U$56, U$58: RX20
U$22: U#BLOX3
U$23, U$24: CS#-<]
U$25, U$52, U$72: PPS0
U$26, U$31: RX#MOSI3
U$27: DSEL0
U$30: QWIIC_4MM
U$33: SFE_LOGO_FLAME_.1
U$34, U$37: TX#MISO1
U$35, U$36: #RST3
U$38, U$41: SCK-(]-04
U$39, U$40: #SAFE1
U$42: RX22
U$43, U$44: PPS5
U$45, U$68: GND3
U$47, U$74: PPS1
U$48, U$70: RTCM5
U$49: ZED#F9P6
U$50, U$55, U$57: TX21
U$51: TX23
U$53, U$69: CORRECTION0
U$59: GPS0
U$65: ACTIVE_L1#L21
U$71, U$75: ANTENNA2
U$73: RTK#SMA4
U$76: GPS#RTK#SMA5

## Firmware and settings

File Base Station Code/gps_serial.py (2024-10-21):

# U-Blox Simple Translator for RTK
# Author: Zack Tokarczyk
#
# This Catches RTCM3 Messages (RTK offsets) and sends them to the machines. It also captures 
# Nav SVIN messages which is information on if the base station has set its reference point and
# Transmits only a subset of messages to the devices. 
#
# The Devices should receieve a message once per second so they will know if they do not have communication.
#
# This will also be used for collecting telemetery from  the devices and will need to be encrypted and
# compressed. This will be refactored later as a communication service.
#
# This is meant to be ran as a linux service with a simple service file and built into a package.
#
# Ublox documentation is here: https://content.u-blox.com/sites/default/files/LAP120_Interfacedescription_UBX-20046191.pdf

import serial
import bitstruct
import struct
from collections import namedtuple

Nav_SVIN = namedtuple('Nav_SVIN', [
        'header1',
        'header2',
        'uclass',
        'id',
        'len',
        'version',
        'iTOW',
        'dur',
        'meanX',
        'meanY',
        'meanZ',
        'meanXHP',
        'meanYHP',
        'meanZHP',
        'meanAcc',
        'obs',
        'valid',
        'active',
        'CK_A',
        'CK_B'
        ])

ser = serial.Serial('/dev/ttyACM0', 57200)  # GPS Set to Base station with learn position set
rem = serial.Serial('/dev/ttyUSB0', 57200)  # Radio Serial
rtcm3 = bytes()
rtcm3_len = 0
ublox = bytes()
ublox_len = 0

def process_ublox(msg: bytes) -> Nav_SVIN:
    return Nav_SVIN._make(struct.unpack('<BBBBHBxxxIIiiibbbxIIbbxxBB', msg))

while True:
    #Read a character at a time
    char = ser.read()

    #Standard Serial Msgs
    if char == b'$':
        line = char + ser.read_until()
        print(line)
        continue
        
    #RTCM3 Messages
    if char == b'\xd3': #RTCM3 Messages begin with 0xD3
        char += ser.read(2)
        data = bitstruct.unpack('u8u6u10', char) 
        rtcm3_len = data[2]
        rtcm3 = char + ser.read(rtcm3_len + 3)
        print(f'RTCM3: {rtcm3}')
        rem.write(rtcm3)
        rcm3 = bytes()
        continue
    
    #If we got here we need 2 chars to know if the message is something we can process.
    char += ser.read()
    #U-Blox Msgs
    if char == b'\xb5b':
        char += ser.read(4)
        swaplen = bitstruct.byteswap('2', char, 4)
        ublox_len = bitstruct.unpack('u16', swaplen)[0]
        ublox = char + ser.read(ublox_len + 2)
        msg = process_ublox(ublox)
        if msg.active == 0:
            rem.write(b'$NA\r\n') # Let the devices know that it isn't active
        if msg.valid == 0:
            rem.write(b'$I\r\n')  # Let the devices know that it isn't valid
        ublox = bytes()
        

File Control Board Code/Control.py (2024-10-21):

# Main Control code
# TODO: make into seperate class imports for MicroPython

import machine
import time

CENTER_NS = 1500000
FORWARD_NS = 2000000
REVERSE_NS = 1000000

PWM_FREQ = 50 #20ms Period
PWM_CENTER_NS = 500000

class Inputs:
    def __init__(self) -> None:
        self.left_track = machine.Pin('D11', machine.Pin.IN)
        self.right_track = machine.Pin('D12', machine.Pin.IN)
        self.actuator_3_control = machine.Pin('D22', machine.Pin.IN) 
        self.actuator_4_control = machine.Pin('D36', machine.Pin.IN)
        self.motor_fault = machine.Pin('D5', machine.Pin.IN)


class Outputs:
    def __init__(self) -> None:
        self.led = machine.Pin('D13', machine.Pin.OUT)
        self.auto = machine.Pin('D4', machine.Pin.OUT)
        self.engine_kill = machine.Pin('D41', machine.Pin.OUT)
        self.engine_start = machine.Pin('D40', machine.Pin.OUT)
        self.motor_left = machine.Pin('D2', machine.Pin.OUT)
        self.motor_right = machine.Pin('D3', machine.Pin.OUT)
        self.actuator_3_motor = machine.Pin('D23', machine.Pin.OUT)
        self.actuator_4_motor = machine.Pin('D37', machine.Pin.OUT)


class PWMInputRead:
    def __init__(self, pin: machine.Pin) -> None:
        self.tick_start = 0
        self.tick_end = 0
        self.pin = pin
        self.delta_us = 0
        self.pin.irq(trigger=machine.Pin.IRQ_RISING | machine.Pin.IRQ_FALLING, handler=self.callback)
        return

    def callback(self, p) -> None:
        if p.value():
            self.tick_start = time.ticks_us()
            return
        self.tick_end = time.ticks_us()
        self.delta_us = time.ticks_diff(self.tick_end, self.tick_start)
        return


class PWMPairs:
    def __init__(self, input: machine.Pin, output: machine.Pin) -> None:
        self.input = input
        self.output = output
        self.pwm_out = machine.PWM(self.output, freq=PWM_FREQ, duty_ns=CENTER_NS)
        self.pwm_in = PWMInputRead(self.input)
        self.read_error_us = 0
        return
    
    def calibrate_input(self) -> None:
        self.pwm_out.duty_ns(CENTER_NS)
        time.sleep(0.1)
        self.read_error_us = CENTER_NS/1000 - self.pwm_in.delta_us
        return
    
    def in_percent(self) -> float:
        return float(((((self.pwm_in.delta_us + self.read_error_us) * 1000) - CENTER_NS)/ PWM_CENTER_NS) * 100.0)
    
    def out_percent(self, percent: float) -> None:
        self.pwm_out.duty_ns(int(percent / 100.0 * PWM_CENTER_NS) + CENTER_NS)
        return


class PWMControl:
    def __init__(self, outputs: Outputs, inputs: Inputs) -> None:
        self.left = PWMPairs(inputs.left_track, outputs.motor_left)
        self.right = PWMPairs(inputs.right_track, outputs.motor_right)
        self.actuator_3 = PWMPairs(inputs.actuator_3_control, outputs.actuator_3_motor)
        self.actuator_4 = PWMPairs(inputs.actuator_4_control, outputs.actuator_4_motor)

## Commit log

2024-07-11 V1.2 Updates
    [Control_board.kicad_pcb, Control_board.kicad_sch, Control_board_V1_0.kicad_pcb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]
2024-07-13 Version 1.2
    Mouser Project: https://www.mouser.com/ProjectManager/ProjectDetail.aspx?AccessID=017e74ae19
    [Control_board.csv, Control_board.kicad_pcb, Control_board.kicad_sch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]
2024-10-20 Swapped Signal and 5+
    [Control_board.kicad_pcb, Control_board.kicad_sch, additions.kicad_sch]
2024-10-20 Example Test Code (MicroPython on teensy4.1)
2024-10-20 Removing Prior Board
    [Control_board_prior.kicad_pcb]
2024-10-20 Updated revision number to 1.3
    This version swapped the +5V and Signal to the motors and from the controller to match the RC standard https://learn.sparkfun.com/tutorials/hobby-servo-tutorial/all where the center is +5V and the pin 3 is the control signal.
    [Control_board.kicad_pcb]
2024-10-20 Update README.md for board setup
2024-10-20 Organizing Folders
    [Control_board.csv, Control_board.kicad_pcb, Control_board.kicad_sch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]

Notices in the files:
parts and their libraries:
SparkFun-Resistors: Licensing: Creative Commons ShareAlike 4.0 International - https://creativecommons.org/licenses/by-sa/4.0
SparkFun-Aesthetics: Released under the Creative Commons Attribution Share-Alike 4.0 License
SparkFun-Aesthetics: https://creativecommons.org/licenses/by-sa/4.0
